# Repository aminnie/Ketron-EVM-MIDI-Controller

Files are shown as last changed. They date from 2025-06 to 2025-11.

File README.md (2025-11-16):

# Ketron EVM Arranger MIDI Controller

This MIDI Controller for the Ketron EVM Sound Module is based on the Adafruit MacroPad RP2040 circuit board:
 
- Adadfruit kits supported: 
   - Macropad Starter kit at https://www.adafruit.com/product/5128 or the
   - Macropad Barebones board at https://www.adafruit.com/product/5100
- Learning more about the Macropad, assembly instructions, and how to download custom code into the device: https://learn.adafruit.com/adafruit-macropad-rp2040. 
- The Starter kit can also be purchased from vendors such as Digikey: https://www.digikey.com/en/products/detail/adafruit-industries-llc/5128/14635377
- Adafruit Midi Library: https://docs.circuitpython.org/projects/midi/en/latest/api.html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
- The Starter kit is an assembly only, and requires no soldering or electronics experience.

The EVM Pad controller is embedded in a custom 3d printed case with low profile key switches and LED window keycaps:

EVMPad

Why use the Macropad RP2040 to control the Ketron? The Macropad has USB HID keyboard drivers - just like the countless keypads you fill find on Amazon. However, these devices and many dedicated MIDI controllers do not support sending MIDI SysEx messages. Ketron exposes a hardware MIDI pedal interface on the EVM, but also has generously provided a MIDI over USB implmenetation. This controller is coded to send MIDI CC and SysEX messages over USB using the Adafruit Circuit Python library.

## EVM Controller HS13+ (Plus):

### Controller Button Configuration

The USB based MIDI Controller supports the most often used Arranger functions via MIDI SysEx and CC messages. Button assignments can be changed by modifying the values in a config file saved on the controller's USB drive. The controller supports a base and shift layer, enabling up to 24 functions to be coded on the keys. 

#### Base layer key assignments

The base layer of the controller is configured to the following EVM SysEx messages:

Row 1:
- Intro/End 1 (green)
- Intro/End 2 (green)
- Intro/End 3 (green)
- To End (red)

Row 2:
- Arr.A (blue)
- Arr.B (blue)
- Arr.C (blue)
- Arr.D (blue)

Row 3:
- Variation/Shift (blue)
- Fill (green)
- Break (orange)
- Start/End (red)

#### Shift layer key assignments

The shift layer of the controller is configured to the following EVM SysEx messages:

Row 1:
- Transpose Up (yellow)
- Transpose Down (yellow)
- Octave Up (teal)
- Octave Down (teal)

Row 2:
- 1/2 Bar (blue)
- Plugged (orange) (drums and bass only macro)
- UnPlugged (orange) (style, real chord and chord only macro)
- RHYTHM (blue) (Rhythm only macro)

Row 3:
- Variation/Shift (blue)
- Value Down (violet)
- Value Up (violet)
- Start/End (red)

#### Activating the Shift Layer
The shift layer operates in two modes - similar to a typical PC keyboard:
- Press the Variation/Shift key, and while holding it in follow up with a second key press for the desired layered function. This combination of keys will transmit the layered MIDI message. This allows for quick activations of e.g. the 1/2 Bar message using the familiar keyboard shift action. More than one layered massage can be sent while the original shift key is held down.
- When you press and hold Variation/Shift for 200ms or longer, the keypad behavior starts activating in a way similar to caps lock on a PC keyboard. The shift layer is activated and keys such as Value Up/Down can be pressed until the Variation/Shift key is pressed again.
- Note: The Variation key continues to support the EVM Arranger Variation function on a quick press (<200ms) and if the above shift conditions are not met.

### Controller Primary Encoder Configuration:

The Encoder switch is coded to cycle through the following functions when pressed. The rotary encode is used to change the values for the selected function.
- Rotor Fast/Slow (blue) - fast or slow, default
- Tempo Up/Down (yellow) - up or down from current Tempo value
- Master Volume Up/Down (purple)

Notes:
- The colors mentioned for the encoder show on the Variation key. When you press Start/Stop, the EVM will start playing and the Variation button turns yellow to indicate that it is in Tempo adjustment mode. The Tempo and Volume modes once activated or pressed are timed to return to the default Rotor Fast/Slow after 60 seconds of no adjustments.
- For Master Volume to work, you must change the EVM configuration to listen on MIDI channel 16. You can do so by navigating to the EVM MIDI configuration screen, select the receive (RX) option, and then set Global to channel 16. The Controller encoder in Volume mode sends MIDI CC Expression to EVM RX Global channel 16 adjusting the volume of all channels in the EVM - acting similar to the EVM Master Volume knob. Also note that an attached MIDI keyboard/organ can be configured to send expression pedal messages to the EVM synchronizing volume between the devices in the same manner.

### Connecting the EVM Controller to your EVM Module:

- The Ketron EVM expects all attached MIDI devices to be powered up before you start it up. It will not detect devices on the USB or MIDI ports that is not switched on or added after EVM power up.
- The Macropad has a single USB port that is used to connect to the EVM, and as a result of the EVM  power up connect requirement, we have to power it via a USB hub or a USB Y Datat and Power Splitter cable that provides external power. 
This is an example USB Hub that works:  Wenter 5 Ports USB 3.0 Hub (https://www.amazon.com/gp/product/B0BMFDLRSQ/ref=ewc_pr_img_1?smid=ATSSJE5RHO7GG&psc=1). The powered USB hub can also be used to charge a tablet if you use that to wirelessly control the EVM. Some Y-splitter USB cables may also work if you prefer to connect a cell phone charger battery for instance to power the unit. See https://www.amazon.com/s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

### Loading customized code into a new Adafruit controller:

See the Adafruit learning website for detailed instructors on how to
-  Prepare the board to load our custom solution in the boot.pym code.py and keymap.cfg files into the controller board.
-  You have the following options after the firmware has been loaded onto the new board:
   - Simply copy the code files from a local disk to the MacroPad USB drive mounted as 'CIRCUITPY'.
   - Use an text editor such as NotePad++ to open the extracted controller files from the download and do a Save-As into the CIRCUITPY drive. This often is the easiest and most reliable way way to update the controller code.
   - Download the Mu Editor to your PC. Mu will connect to the Macropad board and allow you up/download and edit the code.py file. It also has a REPL terminal that can be used to interact with the board during development and debugging and useful if you decide to modify the EVM controller code. 

### Testing the EVM Controller:

Before connecting to the EVM moodule, you may want to download and install MidiView (https://hautetechnique.com/midi/midiview/). MidiView is useful to inspect and validate the output from any MIDI controller. MidiView allows you to monitor the exchange of MIDI messages between any two devices. In this case you will see the EVM controller output the MIDI SysEx and CC messages associated with keys or the rotary encoder.

### Customizing the EVM Cntroller SysEx messages:

Keys are configured by updating the keymap.cfg file on the controller USB drive. Modifying the mappings requires you to lookup the exact text for the required SysEWx MIDI message from either the Tabs (pedal_midis) or Pedal (tab_midis) lookup tables in the Ketron MIDI documentation, and copy it onto one of the keys of the keys. See the config file for the current configuration. Please be careful with the configuration. It is validating and if an error is enountered during startup, all keys will turn red. The unit continues to function though based on the coded defaults. It is preferred that you keep with the Pedal messages. There are many more Tab messages, and for instance Value Up/Down is very useful, but without context it results in unexpected behaviors in the EVM. Carefully test if you pick a value from Tabs other than VARATION. 
Note: The rotary encoder SysEx output is currently hardcoded to tempo up/down,  rotary fast/slow or volume up/down on successive encoder button presses. It is not configurable, but could be done in future if requested.

## EVM Controller HS13+ (Plus):

This version of the EVM controller supports four additional quad encoders used to manage style and voice volumes. The additional four encoders and their built-in switches follow the shift state enabled through the Variation key as explained above. 

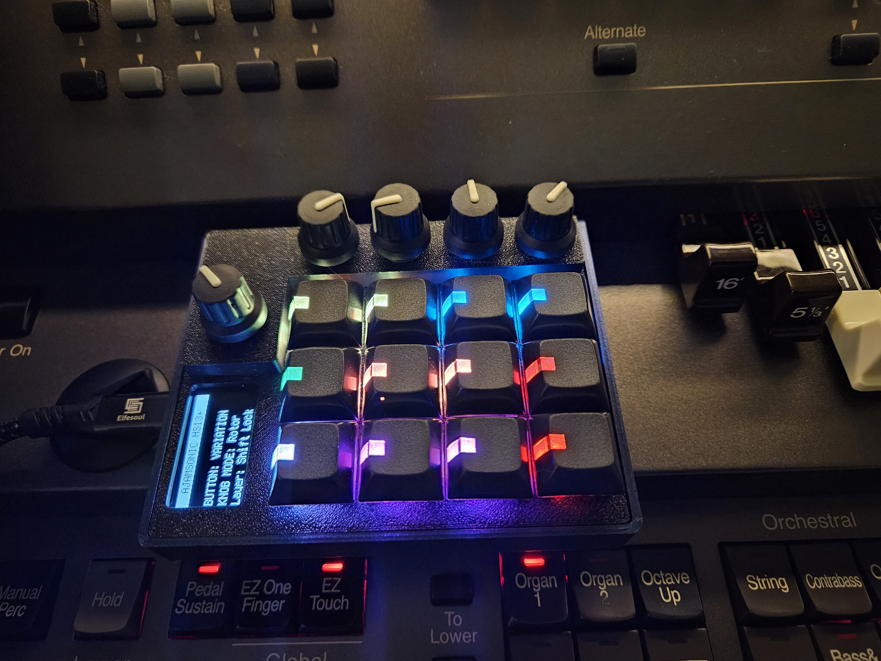
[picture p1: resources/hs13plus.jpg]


### Base layer encoder assignments

Rotary Encoders (left to right):
- Lowers Volume
- Upper/Voice 1 Volume
- Upper/Voice 2 Volume
- Drawbar Volume

Rotary Switches (on each encoder):
- Lowers Volume toggle 0 or 96
- Upper1 Volume toggle 0 or 96
- Upper2 Volume toggle 0 or 96
- Drawbar Volume toggle 0 or 96

### Shift layer encoder assignments

Rotary Encoders (left to right):
- Drum Volume
- Bass Volume
- Chord Volumes
- RealChord Volumes

Rotary Switches (on each encoder):
- Drum Volume toggle 0 or 96
- Bass Volumes toggle 0 or 96
- Chord Volumes toggle 0 or 96
- RealChord Volume toggle 0 or 96

Notes: 
- ‘All Style’ volumes include: Style, Drums, RealChord and Chord
- Volume settings are adjusted relative to the switches options pressed.

#### More versions of this controller:  
- A version of the controller code is also available that emits only MIDI CC messages for instruments that can be coded via MIDI CC messages.

#### Extra:

- Please let me know you need a 3D case for your solution
  - The 3D case .scad and .stl files are available in the case directory if you would like to print it yourself. There are multiple versions of the files for each of the HS13 and HS13+. Each case consists of 3 or more components to be printed.
  - We switched to using low profile key switches and caps you see in the picture. It feels and looks much better. Contact me if I can help.
  - If you plan to print a case and use low profile key switches, then I would recommend you buy the Adafruit Macropad bare bones board only, not the full kit
  - If you have a need to tinker with code.py and try qwiic add-ons, then print the dev 3D case which has a larger slot that accepts a qwiic connector.

Setup with the Roland AT900C, Ketron EVM, iPad EVM Controller, and the out of the box Macropad RP2040:



Original Adafruit Macropad RP2040:



Difference between the Adafruit MacroPad standard order and the custom ordered unit: Low profile key switches and custom key caps. A custom 3D printed case enclosure that hides the electronics components. And of course a MIDI controller solution customized for the Ketron Event series.

For more information, support, or a completed unit please contact: a_minnie@hotmail.com

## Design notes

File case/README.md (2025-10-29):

# Ketron EVM-Button-Controller Enclosure

More details and refinement of the OpenSCAD 3D (https://openscad.org/) design and code to follow.

The EVM HS13 AND HS13+ MacroPad controller enclosure consists of three components:
- Bottom case
  - The PCB and next two layers insert into the bottom case. 
  - The case has openings for the UCB connection as well as the Macropad reset.
- Top cover
  - Keys are inserted into the PCB using the top cover as guide. 
  - The top cover also hides the encoder main body with a seperately printed case (in a seperate file for the HS13)
- Filler layer
  - This layer is inserted in between the top cover laaer and the MacroPad PCB. This closes the gap between the top cover and the PCB and ensures that the latter remains correctly positions.

Assembly Instructions:
- 3D Print/order to print the three layers.
  - Check the opt cover encoder body part to ensure that it is clear of debris.
  - You may need a sharp knife or tool to clear our the encoder body, and a drill body to clean the 6mm shaft hole.
- Lay the top cover on filler layer. 
  - Note the filler layer has bigger openings for the keys than the top cover.
- Unscrew the encoder washer and nut.
- Place the filler layer, and top cover on the PCB, carefully placing the cover over the encoder main body.
  - Replace the encoder washer and nut you removed earlier and lightly tighten the it.
  - If you find that you are unable to get the nut to secure the top cover, then please revisit the step above and clear the top cover encoder body of extra print material.
  - Loosen the nut so that the cover top has a bit of play that helps with inserting the keyswitches
- Insert the 12 key switches into PCB going through the top cover.
  - The PCB has sockets for the keyswitches and no soldering is needed.
  - It will be a tight fir. Ensure you have a compatible key switch, that the pins are straight, and carefully position and insert the keys
  - I start with the middle row centers, followed by the outer corners.
- Insert the PCB assembly into the bottom case.
  - Ensure you have the USB connector aligned with the case USB opening!
  - Insert the PCB assembly at the LCD corner first so that Reset button goes into its respctive whole with out too much pressure
- Use 4 x 3mm screws to secure the bottom case to the PCB and the keyboard assembly.
  - To remobve the keyboard assembly, loosen all four screws, and remove the PCB out of the case by pushing the screws in.
- Insert the encoder knob onto the exposed shaft
  - Press the encoder button a few times and to ensure it is seated correctly.

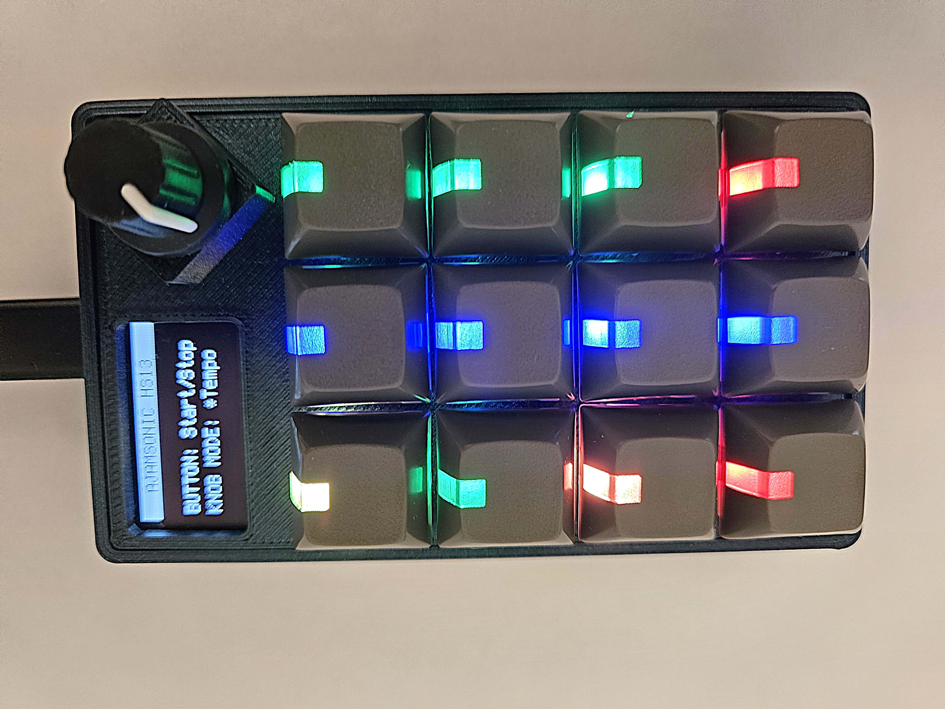
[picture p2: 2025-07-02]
resources/case_live.jpg

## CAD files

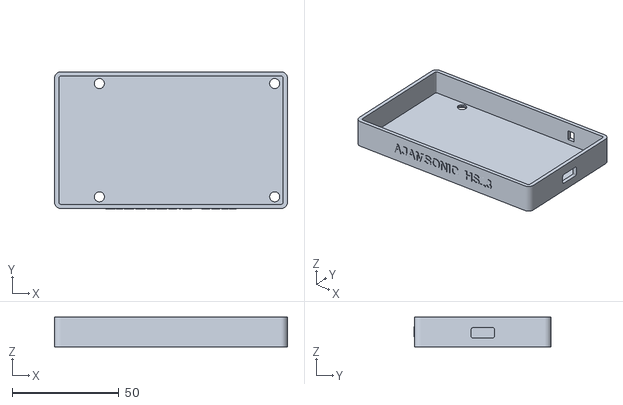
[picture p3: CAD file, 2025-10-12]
case/evm/case_logo.stl
109.0 x 64.3 x 14.0

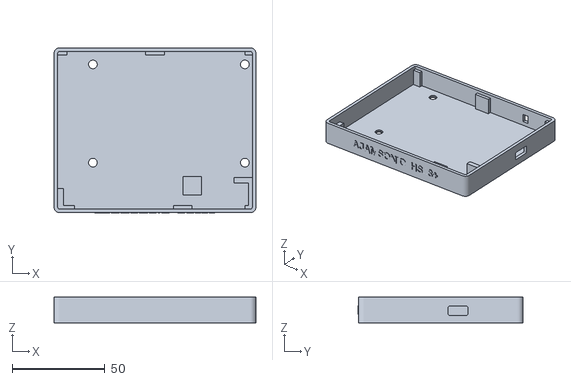
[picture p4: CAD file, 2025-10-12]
case/evmplus/case_plus.stl
109.0 x 89.3 x 14.0

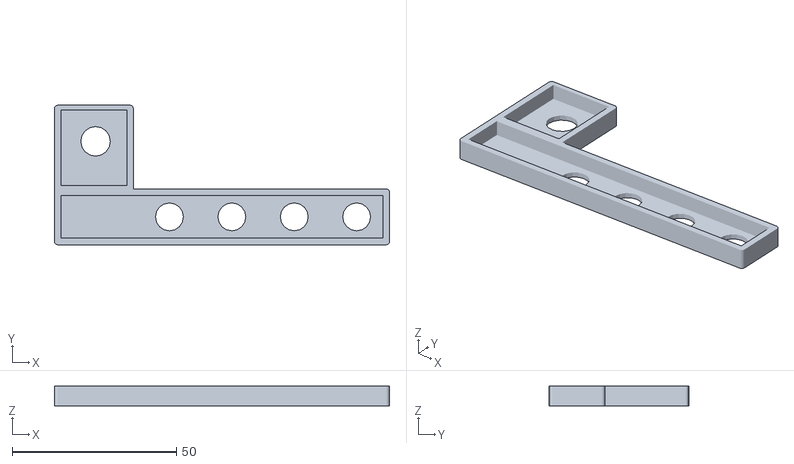
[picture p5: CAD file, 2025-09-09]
case/evmplus/topcover_plus_all_quad_cover.stl
102.0 x 42.5 x 6.00

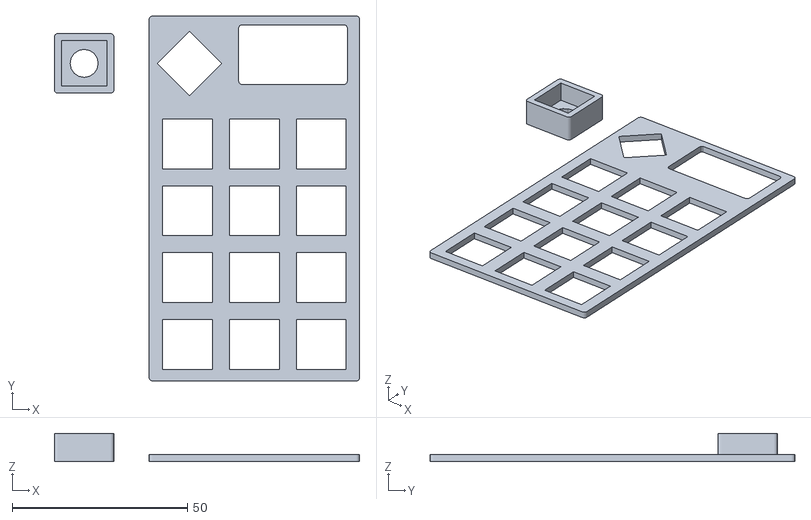
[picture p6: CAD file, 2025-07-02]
case/evm/topcover_reversed.stl
87.0 x 104.0 x 8.00

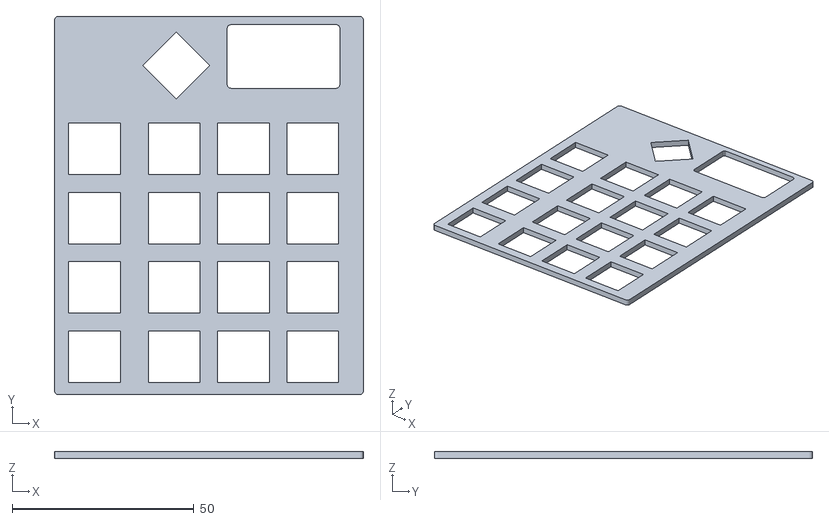
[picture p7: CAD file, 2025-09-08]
case/evmplus/topcover_plus_reversed.stl
85.0 x 104.0 x 2.00

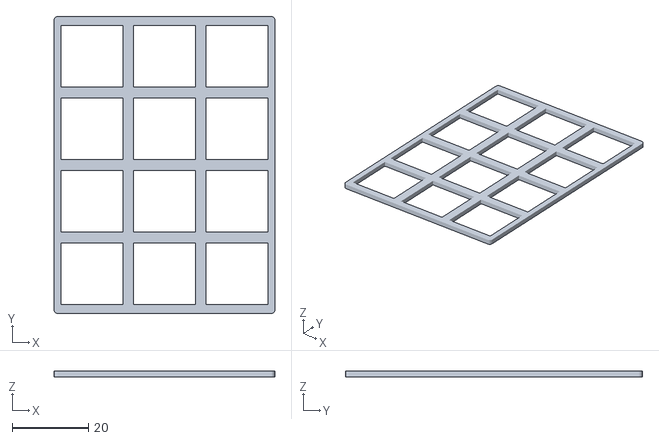
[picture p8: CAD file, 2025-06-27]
case/evm/cover_filler.stl
58.0 x 78.0 x 1.50

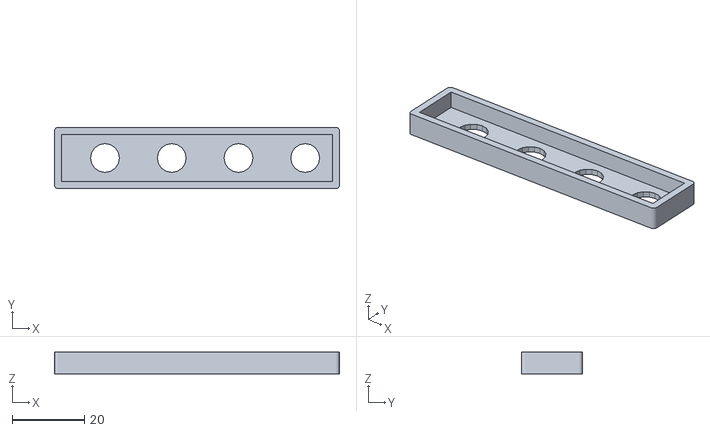
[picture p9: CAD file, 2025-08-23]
case/evmplus/topcover_plus_quad_cover.stl
79.0 x 17.0 x 6.00

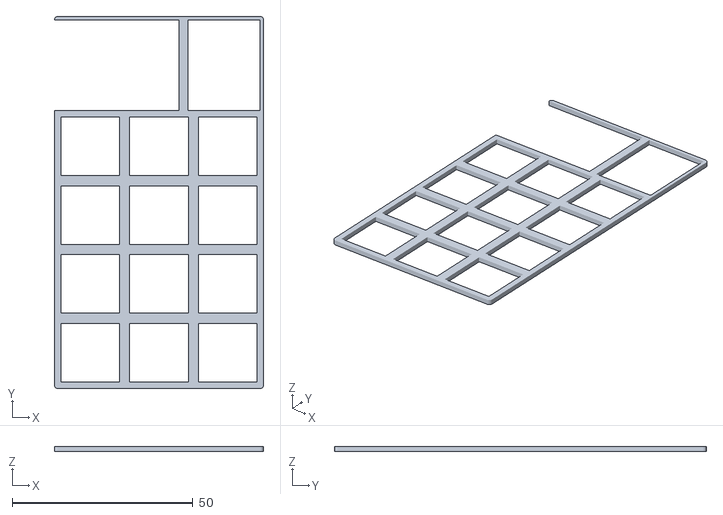
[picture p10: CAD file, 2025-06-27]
case/evm/cover_filler_support.stl
58.0 x 103.0 x 1.50

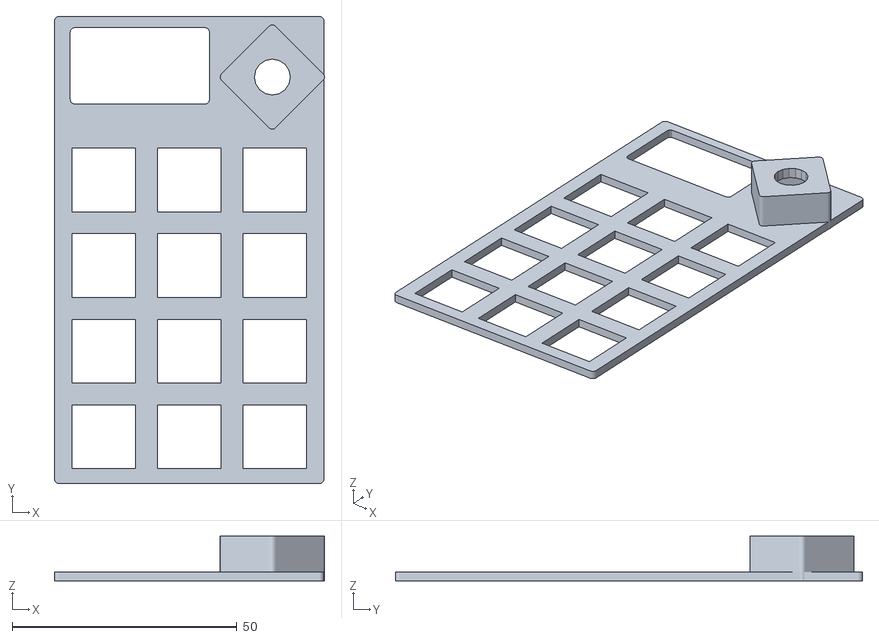
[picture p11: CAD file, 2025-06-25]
case/evm/topcover.stl
60.1 x 104.0 x 10.0

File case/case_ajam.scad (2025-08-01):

// MacroPad RP2040 Case (Bottom and Sides)
// Companion to macropad_top_cover.scad
// Parametric design for Adafruit MacroPad RP2040 keyboard controller
// Author: Generated for CircuitPython EVM Controller project
// License: MIT

// The bottom case along with the filler layer and cover OpenSCAD models provivided
// wraps the Adafruit MacroPad RP2040 in a tightfitting case. The case has a USB port
// the reset button opening, as well as 4 mounting holes to fasten the PCD to the case.

// =============================================================================
// PARAMETERS
// =============================================================================

// Adafruit Macropad RP2040 PCB parameters
pcb_length = 105;          // RP2040 PCB length (mm)
pcb_width = 60;            // RP2040 PCB width (mm)
pcb_thickness = 1.6;       // Standard PCB thickness (mm)
pcb_clearance = 1;         // Space around PCB (mm)
pcb_height_clearance = 8;  // Space above PCB for components (mm)

// Overall case dimensions (should match top cover)
bottom_thickness = 2;      // Thickness of bottom plate (mm)
wall_thickness = 2;        // Thickness of side walls (mm)
corner_radius = 3;         // Rounded corner radius (mm)
inner_corner_radius = 1;   // Rounded inner corner radius

case_length = pcb_length + (wall_thickness * 2);   // Total length of case (mm)
case_width = pcb_width + (wall_thickness * 2);  // Total width of case (mm)
case_height = 14;          // Height of case walls (mm)

// Top cover integration
top_cover_thickness = 3;   // Thickness of top cover (for fit calculation)
top_cover_lip = 1;         // How much top cover overlaps case walls (mm)

// USB port cutout
usb_width = 11;             // Width of USB-C port (mm)
usb_height = 5;            // ** Was 4 - Height of USB-C port (mm)
usb_offset_from_edge = 3;  // Distance from PCB edge to USB center (mm)
usb_position_y = 0;        // Y position along case width (0 = center)
usb_corner_radius = 1;     // Rounded corners for USB hole

// PCB mounting holes keep 2mm for wall in mind
mount_hole_diameter = 4.56;   // Diameter for M3 screws (mm)
mount_hole_positions = [   // [X, Y] positions relative to PCB center
    [-pcb_length/2 + 19, -26.5],   // Bottom left
    [pcb_length/2 - 4, -26.5],   // Bottom right  
    [-pcb_length/2 + 19, 26.5],    // Top left
    [pcb_length/2 - 4, 26.5]     // Top right
];

// Standoffs for PCB mounting
standoff_height = 6;         // Height of PCB standoffs (mm)
standoff_diameter = 5.2;     // Diameter of standoff base (mm)
standoff_hole_diameter = 2.5; // Hole diameter in standoff for screw (mm)

// 3D printing parameters
clearance = 0.2;           // General clearance (mm)
layer_height = 0.2;        // Your 3D printer layer height (mm)

// Catching indent for Cover support lip
cover_lip_indent = [10, 2.5, 2];


// =============================================================================
// MAIN OBJECT
// =============================================================================

difference() {
    union() {
        // Main case body
        case_body();

        ajam_text();
        
        // PCB mounting standoffs
        pcb_standoffs();
    }        

    // Remove internal cavity
    internal_cavity();

    // Remove USB port hole
    usb_port_hole();
    
    // Remove Reset port hole
    reset_port_hole();

    // Remove PCB mounting holes
    pcb_mounting_holes();
}

// Optional: Show PCB position for reference (comment out for final print)
// %pcb_reference();

// =============================================================================
// MODULES (Functions)
// =============================================================================

// Create the main case body with walls
module case_body() {
    // Bottom plate
    hull() {
        // Four corner cylinders for rounded rectangle base
        translate([-(case_length/2 - corner_radius), -(case_width/2 - corner_radius), 0])
            cylinder(h = bottom_thickness, r = corner_radius, $fn = 32);
        
        translate([+(case_length/2 - corner_radius), -(case_width/2 - corner_radius), 0])
            cylinder(h = bottom_thickness, r = corner_radius, $fn = 32);
        
        translate([+(case_length/2 - corner_radius), +(case_width/2 - corner_radius), 0])
            cylinder(h = bottom_thickness, r = corner_radius, $fn = 32);
        
        translate([-(case_length/2 - corner_radius), +(case_width/2 - corner_radius), 0])
            cylinder(h = bottom_thickness, r = corner_radius, $fn = 32);
    }
    
    // Side walls
    difference() {
        // Outer wall
        hull() {
            translate([-(case_length/2 - corner_radius), -(case_width/2 - corner_radius), 0])
                cylinder(h = case_height, r = corner_radius, $fn = 32);
            
            translate([+(case_length/2 - corner_radius), -(case_width/2 - corner_radius), 0])
                cylinder(h = case_height, r = corner_radius, $fn = 32);
            
            translate([+(case_length/2 - corner_radius), +(case_width/2 - corner_radius), 0])
                cylinder(h = case_height, r = corner_radius, $fn = 32);
            
            translate([-(case_length/2 - corner_radius), +(case_width/2 - corner_radius), 0])
                cylinder(h = case_height, r = corner_radius, $fn = 32);
        }
        
        // Inner cavity (removed in main difference)
        translate([0, 0, bottom_thickness])
            hull() {
                inner_radius = corner_radius - wall_thickness;
                inner_length = case_length - 2 * wall_thickness;
                inner_width = case_width - 2 * wall_thickness;
                
                translate([-(inner_length/2 - inner_radius), -(inner_width/2 - inner_radius), 0])
                    cylinder(h = case_height, r = inner_radius, $fn = 32);
                
                translate([+(inner_length/2 - inner_radius), -(inner_width/2 - inner_radius), 0])
                    cylinder(h = case_height, r = inner_radius, $fn = 32);
                
                translate([+(inner_length/2 - inner_radius), +(inner_width/2 - inner_radius), 0])
                    cylinder(h = case_height, r = inner_radius, $fn = 32);
                
                translate([-(inner_length/2 - inner_radius), +(inner_width/2 - inner_radius), 0])
                    cylinder(h = case_height, r = inner_radius, $fn = 32);
            }
    }
    
    // Top cover lip/ledge
    translate([0, 0, case_height - top_cover_thickness]) {
        difference() {
            // Outer ledge
            hull() {
                translate([-(case_length/2 - corner_radius), -(case_width/2 - corner_radius), 0])
                    cylinder(h = top_cover_thickness, r = corner_radius, $fn = 32);
                
                translate([+(case_length/2 - corner_radius), -(case_width/2 - corner_radius), 0])
                    cylinder(h = top_cover_thickness, r = corner_radius, $fn = 32);
                
                translate([+(case_length/2 - corner_radius), +(case_width/2 - corner_radius), 0])
                    cylinder(h = top_cover_thickness, r = corner_radius, $fn = 32);
                
                translate([-(case_length/2 - corner_radius), +(case_width/2 - corner_radius), 0])
                    cylinder(h = top_cover_thickness, r = corner_radius, $fn = 32);
            }
            
            // Inner cutout for top cover
            hull() {
                ledge_radius = corner_radius - top_cover_lip;
                ledge_length = case_length - 2 * top_cover_lip;
                ledge_width = case_width - 2 * top_cover_lip;
                
                translate([-(ledge_length/2 - ledge_radius), -(ledge_width/2 - ledge_radius), -0.5])
                    cylinder(h = top_cover_thickness + 1, r = ledge_radius, $fn = 32);
                
                translate([+(ledge_length/2 - ledge_radius), -(ledge_width/2 - ledge_radius), -0.5])
                    cylinder(h = top_cover_thickness + 1, r = ledge_radius, $fn = 32);
                
                translate([+(ledge_length/2 - ledge_radius), +(ledge_width/2 - ledge_radius), -0.5])
                    cylinder(h = top_cover_thickness + 1, r = ledge_radius, $fn = 32);
                
                translate([-(ledge_length/2 - ledge_radius), +(ledge_width/2 - ledge_radius), -0.5])
                    cylinder(h = top_cover_thickness + 1, r = ledge_radius, $fn = 32);
            }
        }
    }
}
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

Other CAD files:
case/evm/case_dev.stl
case/evm/case.stl
case/evm/case.scad
case/evm/case_dev.scad
case/evm/case_logo.scad
case/evm/cover_filler.scad
case/evm/cover_filler_support.scad
case/evm/macropad_topcover_reversed.scad
case/evm/topcover.scad
case/evm/topcover_reversed.scad
case/evmplus/case_plus.scad
case/evmplus/topcover_plus_all_quad_cover.scad
case/evmplus/topcover_plus_quad_cover.scad
case/evmplus/topcover_plus_reversed.scad
case/keycaps/evm_keycap_topcover_clear.scad
case/keycaps/evm_transparent_keycap_insert.scad
case/keycaps/roundedcubes.scad

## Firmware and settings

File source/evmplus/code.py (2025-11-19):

# Ketron EVM Arranger Controller - Plus

import board, displayio, digitalio
import terminalio
import time

from adafruit_display_text import bitmap_label as label
from adafruit_displayio_layout.layouts.grid_layout import GridLayout
from adafruit_macropad import MacroPad

import usb_midi
import adafruit_midi
from adafruit_midi.control_change import ControlChange
from adafruit_midi.note_off import NoteOff
from adafruit_midi.note_on import NoteOn
from adafruit_midi.system_exclusive import SystemExclusive

from rainbowio import colorwheel

import adafruit_seesaw.digitalio
import adafruit_seesaw.neopixel
import adafruit_seesaw.rotaryio
import adafruit_seesaw.seesaw

# Set to FALSE for no startup test
TEST_CONNECT = False

# --- Constants and Enums ---
class EncoderMode:
    ROTOR = 0
    TEMPO = 1
    VOLUME = 2
    VALUE = 3

class MIDIType:
    PEDAL = 0
    TAB = 1
    MACRO = 2
    
class MIDIStatus:
    OFF = 0x00
    ON = 0x7F

class EncoderMode:
    ROTOR = 0
    TEMPO = 1
    VOLUME = 2
    VALUE = 3

class ShiftKeyMode:
    OFF = 0
    PENDING = 1
    ACTIVE_SHIFT = 2
    ACTIVE_LOCK = 3

class EFXLevel:
    Voice1 = 0x07
    Voice2 = 0x3D
    RealChord = 0x08
    LeftGM = 0x3F

# Manage Control Panel Volume Sliders via midi CC
class SliderCC:
    PLAYER_CC = 0x66   #CC 102
    STYLE_CC = 0x67
    DRUM_CC = 0x68
    BASS_CC = 0x69
    CHORD_CC = 0x6A
    REALCHORD_CC = 0x6B
    LOWERS_CC = 0x6C
    USER2_CC = 0x6D
    USER3_CC = 0x6E
    VOICE1_CC = 0x72     #CC 114
    VOICE2_CC = 0x73
    DRAWBARS_CC = 0x74
    MICRO1_CC = 0x75
    VOCAL_CC = 0x76

class Colors:
    WHITE = 0x606060
    BLUE = 0x000020
    GREEN = 0x002000
    RED = 0x200000
    ORANGE = 0x701E02
    PURPLE = 0x800080
    YELLOW = 0x808000
    TEAL = 0x004040
    OFFWHITE = 0xA47474

# Color mapping dictionary
COLOR_MAP = {
    'red': Colors.RED,
    'green': Colors.GREEN,
    'blue': Colors.BLUE,
    'purple': Colors.PURPLE,
    'yellow': Colors.YELLOW,
    'orange': Colors.ORANGE,
    'white': Colors.WHITE,
    'teal': Colors.TEAL,
    'offwhite': Colors.OFFWHITE
}

# Key used to trigger test tune
TUNE_KEY = 11

# --- Configuration Class ---
class EVMConfig:
    def __init__(self):
        #self.display_banner =     "   Ketron EVM Plus   "
        #self.display_sub_banner = "Arranger Controller "
        #self.version = "1.2"
        self.display_banner =     "   AJAMSONIC HS13+   "
        self.display_sub_banner = "Pad Controller   "
        self.version = "1.2.0"

        # USB port on the left side of the MacroPad
        self.usb_left = True

        # MIDI Out Channel to be matched in EVM Global RX
        self.midi_out_channel = 15
        
        # Key used to reflect timed Eccoder mode changes on LED
        # Enable or disable Layer Shift Mode for users who prefer single layer only 
        self.key_variation = 0
        self.shift_enable = True

        # Timers for tempo, volume, key brightness, etc
        self.key_bright_timer = 0.20
        self.shift_hold_timer = 0.25

        self.tempo_timer = 60
        self.volume_timer = 60
        self.value_timer = 60
        self.version_timer = 15
        self.tune_hold_timer = 2
        
        # Quad Encoder configs loaded from keymap.cfg
        self.is_quadencoder = True
        self.encoder_step = 8
        self.encoder_fwd = True
        self.encoder_grad = False
        self.encoder_vol = 96

        self.quad_switch_timer = .5
        
        # Quad encoder variables
        self.quad_encoders = []
        self.quad_switches = []
        self.quad_switches_toggle = []
        self.quad_pixels = []

        # Initialize MacroPad key mappings
        self.key_map = [0, 1, 2, 3, 4, 5, 6, 7, 8, 9, 10, 11]
        if not self.usb_left:
            self.key_map = [11 - i for i in range(12)]

    def get_key(self, key):
        """Safe key mapping with bounds checking"""
        
        if key < 0 or key > 11:
            print("Invalid key map request: {}".format(key))
            return 0
        return self.key_map[key]

# --- MIDI Handler Class ---
class MIDIHandler:
    def __init__(self, midi_instance, config, key_cache):
        self.midi = midi_instance
        self.config = config
        self.key_cache = key_cache
        
        self.manufacturer_id_pedal = bytearray([0x26, 0x79])
        self.manufacturer_id_tab = bytearray([0x26, 0x7C])
        self.manufacturer_id_efx = bytearray([0x26, 0x7B])
        
        # Pre-allocate bytearrays for memory efficiency
        self.pedal_sysex_1 = bytearray([0x03, 0x00, 0x00])
        self.pedal_sysex_2 = bytearray([0x05, 0x00, 0x00, 0x00])
        self.tab_sysex = bytearray([0x00, 0x00])

        # EFX Level/Volume
        self.efx_level_sysex = bytearray([0x00, 0x05, 0x00])

        self.cur_volume = 100

    def send_pedal_sysex(self, midi_value):
        """Send SysEx for Pedal commands"""
        
        try:
            # Send ON followed by OFF Message
            if midi_value < 128:
                self.pedal_sysex_1[1] = midi_value
                self.pedal_sysex_1[2] = MIDIStatus.ON
                sysex_message = SystemExclusive(self.manufacturer_id_pedal, self.pedal_sysex_1)
                self.midi.send(sysex_message)

                self.pedal_sysex_1[2] = MIDIStatus.OFF
                sysex_message = SystemExclusive(self.manufacturer_id_pedal, self.pedal_sysex_1)
                self.midi.send(sysex_message)
            else:
                self.pedal_sysex_2[1] = (midi_value >> 7) & 0x7F
                self.pedal_sysex_2[2] = midi_value & 0x7F
                self.pedal_sysex_2[3] = MIDIStatus.ON
                sysex_message = SystemExclusive(self.manufacturer_id_pedal, self.pedal_sysex_2)
                self.midi.send(sysex_message)

                self.pedal_sysex_2[3] = MIDIStatus.OFF
                sysex_message = SystemExclusive(self.manufacturer_id_pedal, self.pedal_sysex_2)
                self.midi.send(sysex_message)
            return True
        except Exception as e:
            print("Error sending pedal SysEx: {}".format(e))
            return False

    def send_tab_sysex(self, midi_value):
        """Send SysEx for Tab commands"""
        
        try:
            self.tab_sysex[0] = midi_value
            self.tab_sysex[1] = MIDIStatus.ON
            sysex_message = SystemExclusive(self.manufacturer_id_tab, self.tab_sysex)
            self.midi.send(sysex_message)

            self.tab_sysex[1] = MIDIStatus.OFF
            sysex_message = SystemExclusive(self.manufacturer_id_tab, self.tab_sysex)
            self.midi.send(sysex_message)
            return True
        except Exception as e:
            print("Error sending tab SysEx: {}".format(e))
            return False

    def send_macro_sysex(self, midi_key):
        """Send one or more macro list values as SysEx Pedal or Tab message(s)"""

        try:
            
            for macro, items in self.key_cache.user_macro_midis.items():
                #print(f"Macro: {macro}")
                if macro == midi_key:
                    for item in items:
                        #print(f"  - {item}")
                        if ':' in item:
                            macro_parts = item.split(':')
                            #print(f"macro_parts: {macro_parts}")
                            if len(macro_parts) >= 2:
                                lookup_key = int(macro_parts[0].strip())
                                value = macro_parts[1].strip()

                                if lookup_key == MIDIType.PEDAL:
                                    hex_value = self.key_cache.pedal_midis.get(value, "")
                                    if hex_value:
                                        self.send_pedal_sysex(hex_value)
                                elif lookup_key == MIDIType.TAB:
                                    hex_value = self.key_cache.tab_midis.get(value, "")                            
                                    if hex_value:
                                        self.send_tab_sysex(hex_value)
            return True
        except Exception as e:
            print("Error sending macros SysEx: {}".format(e))
            return False

    def send_master_volume(self, config, updown):
        """Send volume control via CC11"""
        self.config = config
        
        try:
            # Change volume in 8-unit increments
            if updown == -1:
                self.cur_volume = max(0, self.cur_volume - 8)
            else:
                self.cur_volume = min(127, self.cur_volume + 8)

            self.midi.send(ControlChange(11, self.cur_volume), channel=self.config.midi_out_channel)
            return True
        except Exception as e:
            print("Error sending volume: {}".format(e))
            return False

    def send_quad_volume(self, config, volume):
        """Send volume CC for Quad Encoder on special EVM CCs"""
        self.config = config
        
        try:
            self.midi.send(ControlChange(11, volume), self.config.midi_out_channel)
        except Exception as e:
            print("Error sending volume: {}".format(e))
            return False        

    def send_quad_cc_volume(self, ccCode, volume, midi_channel):
        """Send volume CC for Quad Encoder configured channels"""
        
        try:
            self.midi.send(ControlChange(ccCode, volume), midi_channel)
        except Exception as e:
            print("Error sending volume: {}".format(e))
            return False        

    def send_efxlevel_sysex(self, efxcode, volume):
        """Send SysEx EFX Level/Volume commands"""
        
        try:
            self.efx_level_sysex[0] = efxcode
            self.efx_level_sysex[2] = volume
            sysex_message = SystemExclusive(self.manufacturer_id_efx, self.efx_level_sysex)
            self.midi.send(sysex_message)

            return True
        except Exception as e:
            print("Error sending EFX Level SysEx: {}".format(e))
            return False

    def test_connectivity(self):
        """Test MIDI connectivity with audible notes"""
        
        try:
            # Notes for a short segment of "Ode to Joy"
            # Using MIDI note numbers (C4=60, D4=62, E4=64, F4=65, G4=67, A4=69, B4=71, C5=72)
            notes = [64, 64, 65, 67, 67, 65, 64, 62, 60, 60, 62, 64, 64, 62, 62] 
            durations = [0.4] * len(notes)       

            for note, duration in zip(notes, durations):
                self.midi.send(NoteOn(note, 120))
                time.sleep(duration)
                self.midi.send(NoteOff(note, 0))
                time.sleep(duration/4)
            return True
        except Exception as e:
            print("MIDI test failed: {}".format(e))
            return False

# --- Key Lookup Cache for Performance ---
class KeyLookupCache:
    def __init__(self, config):
        self.config = config
        self.cache = {}
        self.cache_shift = {}

        # Initialize MacroPad key & color mappings to default MIDI message values
        # USB drive keymap.cfg file will override if present
        self.macropad_key_map = [
            "1:VARIATION", "0:Arr.A", "0:Intro/End1", "0:Fill",
            "0:Arr.B", "0:Intro/End2","0:Break", "0:Arr.C",
            "0:Intro/End3", "0:Start/Stop", "0:Arr.D", "0:To End"
        ]
        self.macropad_color_map = [
            Colors.BLUE, Colors.BLUE, Colors.GREEN, Colors.GREEN,
            Colors.BLUE, Colors.GREEN, Colors.ORANGE, Colors.BLUE,
            Colors.GREEN, Colors.RED, Colors.BLUE, Colors.RED
        ]

        self.macropad_key_map_shift = [
            "1:VARIATION", "0:Low. Mute", "1:TRANSP_DOWN", "0:HALF BAR",
            "0:FILL & DRUM IN", "1:TRANSP_UP", "0:Arr.Off", "2:UNPLUGGED",
            "1:OCTAVE_DOWN", "0:Start/Stop", "2:PLUGGED", "1:OCTAVE_UP"
        ]
        self.macropad_color_map_shift = [
            Colors.RED, Colors.BLUE, Colors.YELLOW, Colors.PURPLE,
            Colors.GREEN, Colors.YELLOW, Colors.RED, Colors.ORANGE,
            Colors.TEAL, Colors.RED, Colors.ORANGE, Colors.TEAL
        ]

        self.user_macro_midis = {
            "UNPLUGGED":["0:FILL & DRUM IN"],
            "PLUGGED":["0:Drum Mute"],
            "FArr.A":["1:FILL","0:Arr.A"],
            "FArr.B":["1:FILL","0:Arr.B"],
            "FArr.C":["1:FILL","0:Arr.C"],
            "FArr.D":["1:FILL","0:Arr.D"],
            "SStop":["0:Start/Stop"],
            "SStop":["0:Start/Stop"],
            "SStop":["0:Start/Stop"],
            "SStop":["0:Start/Stop"]
        }

        # Ketron Pedal and Tab MIDI lookup dictionaries
        self.pedal_midis = self._init_pedal_midis()
        self.tab_midis = self._init_tab_midis()
        self.cc_midis = self._init_cc_midis()

        self._build_cache()

    def _init_pedal_midis(self):
        """Initialize pedal MIDI dictionary"""
        
        return {
            "Sustain": 0x00, "Soft": 0x01, "Sostenuto": 0x02, "Arr.A": 0x03,
            "Arr.B": 0x04, "Arr.C": 0x05, "Arr.D": 0x06, "Fill1": 0x07,
            "Fill2": 0x08, "Fill3": 0x09, "Fill4": 0x0A, "Break1": 0x0B,
            "Break2": 0x0C, "Break3": 0x0D, "Break4": 0x0E, "Intro/End1": 0x0F,
            "Intro/End2": 0x10, "Intro/End3": 0x11, "Start/Stop": 0x12,
            "Tempo Up": 0x13, "Tempo Down": 0x14, "Fill": 0x15, "Break": 0x16,
            "To End": 0x17, "Bass to Lowest": 0x18, "Bass to Root": 0x19,
            "Live Bass": 0x1A, "Acc.BassToChord": 0x1B, "Manual Bass": 0x1C,
            "Voice Lock Bass": 0x1D, "Bass Mono/Poly": 0x1E, "Dial Down": 0x1F,
            "Dial Up": 0x20, "Auto Fill": 0x21, "Fill to Arr.": 0x22,
            "After Fill": 0x23, "Low. Hold Start": 0x24, "Low. Hold Stop": 0x25,
            "Low. Hold Break": 0x26, "Low. Stop Mute": 0x27, "Low. Mute": 0x28,
            "Low. and Bass": 0x29, "Low. Voice Lock": 0x2A, "Pianist": 0x2B,
            "Pianist Auto/Stand.": 0x2C, "Pianist Sustain": 0x2D, "Bassist": 0x2E,
            "Bassist Easy/Exp.": 0x2F, "Key Start": 0x30, "Key Stop": 0x31,
            "Enter": 0x32, "Exit": 0x33, "Registration": 0x34, "Fade": 0x35,
            "Harmony": 0x36, "Octave Up": 0x37, "Octave Down": 0x38,
            "RestartCount In": 0x39, "Micro1 On/Off": 0x3A, "Micro1 Down": 0x3B,
            "Micro1 Up": 0x3C, "Voicetr.On/Off": 0x3D, "Voicetr.Down": 0x3E,
            "Voicetr.Up": 0x3F, "Micro2 On/Off": 0x40, "EFX1 On/Off": 0x41,
            "EFX2 On/Off": 0x42, "Arabic.Set1": 0x43, "Arabic.Set2": 0x44,
            "Arabic.Set3": 0x45, "Arabic.Set4": 0x46, "Dry On Stop": 0x47,
            "Pdf Page Down": 0x48, "Pdf Page Up": 0x49, "Pdf Scroll Down": 0x4A,
            "Pdf Scroll Up": 0x4B, "Glide Down": 0x4C, "Lead Mute": 0x4D,
            "Expr. Left/Style": 0x4E, "Arabic Reset": 0x4F, "Hold": 0x50,
            "2nd On/Off": 0x51, "Pause": 0x52, "Talk On/Off": 0x53,
            "Manual Drum": 0x54, "Kick Off": 0x55, "Snare Off": 0x56,
            "Rimshot Off": 0x57, "Hit-Hat Off": 0x58, "Cymbal Off": 0x59,
            "Tom Off": 0x5A, "Latin1 Off": 0x5B, "Latin2 Off": 0x5C,
            "Latin3/Tamb Off": 0x5D, "Clap/fx Off": 0x5E, "Voice Down": 0x5F,
            "Voice Up": 0x60, "Regis Down": 0x61, "Regis Up": 0x62,
            "Style Voice Down": 0x63, "Style Voice Up": 0x64, "EFX1 Preset Down": 0x65,
            "EFX1 Preset Up": 0x66, "Multi": 0x67, "Page<<": 0x68, "Page>>": 0x69,
            "RegisVoice<<": 0x6A, "RegisVoice>>": 0x6B, "Text Page": 0x6E,
            "Text Page+": 0x6F, "Style Voice 1": 0x70, "Style Voice 2": 0x71,
            "Style Voice 3": 0x72, "Style Voice 4": 0x73, "VIEW & MODELING": 0x74,
            "Lock Bass": 0x75, "LockChord": 0x76, "Lyrics": 0x77,
            "VoiceToABCD": 0x87, "TAP": 0x88, "Autocrash": 0x89,
            "Transp Down": 0x8A, "Transp Up": 0x8B, "Text Record": 0x8C,
            "Bass & Drum": 0x8D, "Pdf Clear": 0x8E, "Record": 0x90, "Play": 0x91,
            "DoubleDown": 0x92, "DoubleUp": 0x93, "Arr.Off": 0x94,
            "FILL & DRUM IN": 0x95, "Wah to Pedal": 0x96, "Overdrive to Pedal": 0x98,
            "Drum Mute": 0x99, "Bass Mute": 0x9A, "Chords Mute": 0x9B,
            "Real Chords Mute": 0x9C, "Voice2 to Pedal": 0x9D, "Micro Edit": 0x9E,
            "Micro2 Edit": 0x9F, "HALF BAR": 0xA0, "Bs Sust Pedal": 0xA1,
            "Scale": 0xA2, "End Swap": 0xA3, "Set Down": 0xA4, "Set Up": 0xA5,
            "FswChDelay": 0xA6, "IntroOnArr.": 0xA7, "EndingOnArr.": 0xA8,
            "Arr. Down": 0xA9, "Arr. Up": 0xAA, "Ending1": 0xAB, "Ending2": 0xAC,
            "Ending3": 0xAD, "Bass Lock": 0xAE, "Intro Loop": 0xB0,
            "Scene Down": 0xB1, "Scene Up": 0xB2, "STEM Scene A": 0xB3,
            "STEM Scene B": 0xB4, "STEM Scene C": 0xB5, "STEM Scene D": 0xB6,
            "STEM Solo": 0xB7, "STEM Autoplay": 0xB8, "STEM A On/Off": 0xB9,
            "STEM B On/Off": 0xBA, "STEM C On/Off": 0xBB, "STEM D On/Off": 0xBC,
            "STEM Lead On/Off": 0xBD, "Art. Toggle": 0xBE, "Key Tune On/Off": 0xBF,
            "Txt Clear": 0xC0, "Voicetr. Edit": 0xC1, "Clear Image": 0xC2
        }

    def _init_tab_midis(self):
        """Initialize tab MIDI dictionary"""
        
        return {
            "DIAL_DOWN": 0x0, "DIAL_UP": 0x1, "PLAYER_A": 0x2, "PLAYER_B": 0x3,
            "ENTER": 0x4, "MENU": 0x6, "LYRIC": 0x7, "LEAD": 0x8, "VARIATION": 0x9,
            "DRAWBARS_VIEW": 0x0a, "DRAWBARS": 0x10, "DRUMSET": 0x11, "TALK": 0x12,
            "VOICETRON": 0x13, "STYLE_BOX": 0x14, "VOICE1": 0x19, "VOICE2": 0x1a,
            "USER_VOICE": 0x1b, "XFADE": 0x1c, "INTRO1": 0x1d, "INTRO2": 0x1e,
            "INTRO3": 0x1f, "BASSIST": 0x20, "DRUM_MIXER": 0x22, "OCTAVE_UP": 0x24,
            "OCTAVE_DOWN": 0x25, "USER_STYLE": 0x26, "DSP": 0x27, "ADSR_FILTER": 0x28,
            "MICRO": 0x29, "ARRA": 0x2c, "ARRB": 0x2d, "ARRC": 0x2e, "ARRD": 0x2f,
            "FILL": 0x30, "BREAK": 0x31, "JUKE_BOX": 0x32, "STEM": 0x33,
            "PIANIST": 0x34, "BASS_TO_LOWEST": 0x40, "MANUAL_BASS": 0x41,
            "PORTAMENTO": 0x48, "HARMONY": 0x49, "PAUSE": 0x4a, "TEMPO_SLOW": 0x4b,
            "TEMPO_FAST": 0x4c, "START_STOP": 0x4d, "TRANSP_DOWN": 0x59,
            "TRANSP_UP": 0x5a, "AFTERTOUCH": 0x5e, "EXIT": 0x5f, "ROTOR_SLOW": 0x60,
            "ROTOR_FAST": 0x61, "PIANO_FAM": 0x62, "ETHNIC_FAM": 0x63,
            "ORGAN_FAM": 0x64, "GUITAR_FAM": 0x65, "BASS_FAM": 0x66,
            "STRING_FAM": 0x67, "BRASS_FAM": 0x68, "SAX_FAM": 0x69, "HOLD": 0x6f,
            "PAD_FAM": 0x70, "SYNTH_FAM": 0x71, "FADEOUT": 0x73, "BASS_TO_ROOT": 0x74,
            "GM": 0x77
        }

    def _init_cc_midis(self):
        """Initialize MIDI CC dictionary"""
        
        return {
            "PLAYER": SliderCC.PLAYER_CC, "STYLE": SliderCC.STYLE_CC, "DRUM": SliderCC.DRUM_CC, 
            "CHORD": SliderCC.CHORD_CC, "REALCHORD": SliderCC.REALCHORD_CC, 
            "BASS": SliderCC.BASS_CC, "LOWERS": SliderCC.LOWERS_CC, "USER2": SliderCC.USER2_CC, "USER3": SliderCC.USER3_CC, 
            "VOICE1": SliderCC.VOICE1_CC, "VOICE2": SliderCC.VOICE2_CC, "DRAWBARS": SliderCC.DRAWBARS_CC,
            "MICRO1": SliderCC.MICRO1_CC, "VOCAL": SliderCC.VOCAL_CC
    }


    def _build_cache(self):
        """Build lookup cache at startup"""
        
        # Build Default layer cache
        for i in range(12):
            key_id = self.config.get_key(i)
            mapped_key = self.macropad_key_map[key_id]

            if mapped_key and len(mapped_key) > 2 and mapped_key[1] == ':':
                try:
                    lookup_key = int(mapped_key[0])
                    midi_key = mapped_key[2:]

                    if lookup_key == MIDIType.PEDAL:
                        midi_value = self.pedal_midis.get(midi_key, 0)
                    else:
                        midi_value = self.tab_midis.get(midi_key, 0)

                    self.cache[i] = (lookup_key, midi_key, midi_value)
                except (ValueError, IndexError):
                    print("Error caching key {}: {}".format(i, mapped_key))
                    self.cache[i] = (0, "", 0)
            else:
                self.cache[i] = (0, "", 0)

        # Build Shift Layer cache
        for i in range(12):
            key_id = self.config.get_key(i)
            mapped_key = self.macropad_key_map_shift[key_id]

            if mapped_key and len(mapped_key) > 2 and mapped_key[1] == ':':
                try:
                    lookup_key = int(mapped_key[0])
                    midi_key = mapped_key[2:]

                    if lookup_key == MIDIType.PEDAL:
                        midi_value = self.pedal_midis.get(midi_key, 0)
                    else:
                        midi_value = self.tab_midis.get(midi_key, 0)

                    self.cache_shift[i] = (lookup_key, midi_key, midi_value)
                except (ValueError, IndexError):
                    print("Error caching shift key {}: {}".format(i, mapped_key))
                    self.cache_shift[i] = (0, "", 0)
            else:
                self.cache_shift[i] = (0, "", 0)

    def get_key_midi(self, key_id, shift_mode):
        """Get cached MIDI data for key"""
        
        if (shift_mode == ShiftKeyMode.ACTIVE_SHIFT) or (shift_mode == ShiftKeyMode.ACTIVE_LOCK):
            return self.cache_shift.get(key_id, (0, "", 0))
        else:
            return self.cache.get(key_id, (0, "", 0))

    def validate_color_string(self, color_string):
        """Validate and return color code"""
        
        return COLOR_MAP.get(color_string.lower(), Colors.WHITE)
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

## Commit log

2025-03-27 Update code.py
    Add Encoder switch to alternate between Tempo and Dial Up/Down SysEx messages
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2025-04-30 Updated Rotary Dial to support both ROTOR and TEMPO
    Use rotory dail click function to toggle between functions.
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2025-06-15 Default keysconfig.txt
    [keysconfig.txt]
2025-06-16 Update keysconfig.txt to handle key color spec
    [keysconfig.txt]
2025-06-17 Update after code review refactoring
    [keysconfig.txt]
2025-06-17 Update README.md and Code Refactoring/Optimization
    # EVMController.py - Code Review and Implementation Changes
    # Date: January 2025
    # CircuitPython/Python 2.7 Optimization for Ketron EVM Controller
    ## OVERVIEW
    This document outlines the comprehensive refactoring and optimization of EVMController.py
    for improved performance, maintainability, and robustness in CircuitPython environments.
    ## 🏗️ STRUCTURAL IMPROVEMENTS IMPLEMENTED
    ### 1. Configuration Management
    **NEW: EVMConfig Class**
    - Centralized all configuration settings (timers, display text, USB orientation)
    - Safe key mapping with bounds checking and error handling
    - **FIXED: 180-degree key rotation** - Physical la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
2025-06-18 Fixed error when the keys config file missing
    [code.py]
2025-06-18 Initial commit
    Cursor and Claude generated case first pass
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2025-06-18 Rename source code directory
    [keysconfig.txt]
2025-06-18 Renamed to .scad
    [macropad_case.scad, macropad_topcover.scad]
2025-06-19 Updated initial case designs
    [macropad_case.scad, macropad_topcover.scad]
2025-06-19 Update before first print
    [macropad_case.scad, macropad_topcover.scad]
2025-06-21 Updated case and case top
    [macropad_case.scad, macropad_case.stl, macropad_topcover.scad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]
2025-06-22 Case and top cover V1.0
    [macropad_case.scad, macropad_case.stl, macropad_topcover.scad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]
2025-06-22 Case refinement updates - case mounting holes
    [macropad_case.scad, macropad_case.stl, macropad_topcover.scad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]
2025-06-23 Created new cover filler to close gap between board and cover
    [cover_filler.scad, cover_filler.stl]
2025-06-24 Created QWIIC + reset slot. Took the right side case feet in 0.5mm for better fit to board.
    [macropad_case.stl, macropad_case_dev.scad, macropad_case_dev.stl]
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2025-06-25 Case incremental update
    [macropad_case.stl, macropad_topcover.scad, macropad_topcover.stl]
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2025-06-27 Added more extensive filler layer option
    [cover_filler.stl, cover_filler_support.scad, cover_filler_support.stl]
2025-07-02 Added comments to the OpenSCAD files
    [cover_filler.scad, cover_filler_support.scad, macropad_case.scad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]
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2025-07-02 Created a new reverse cover with bottom up
    [macropad_topcover_reversed.scad, macropad_topcover_reversed.stl]
2025-07-04 Add AJAMSONIC banner
    [keysconfig.txt]
2025-07-12 Renamed the case files
    [case.scad, case.stl, case_dev.scad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]
2025-07-21 Update the development case to enlarge the I2C port
    [case_dev.scad, case_dev.stl]
2025-07-30 Created Genos Controller
    [keysconfig.txt]
2025-08-01 Initial working version of the Genos Controller
    [case_ajam.scad, case_ajam.stl, keysconfig.txt]
2025-08-02 Quad Encoder Initialization volume reset on init
    [code.py]
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2025-08-05 Logo add to case
    [case_ajam.stl, case_logo.scad, case_logo.stl]
2025-08-10 EVM Plus new case
    [case_plus.scad, case_plus.stl, topcover_plus_reversed.scad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]
2025-08-16 Corrected Genos key to note mappings
    [code.py]
2025-08-17 Added layered key configs
    [keysconfig.txt]
2025-08-17 Changed key config file name for new adds
    [keymap.cfg, keysconfig.txt]
2025-08-18 Changed key config file name for new layer adds
    [keymap.cfg]
2025-08-18 Update keys config file removing error in mappings
    [keymap.cfg]
2025-08-19 Corrected a lookup issue in Genos controller
    [keysconfig.txt]
2025-08-23 New Quad Encoder increment limits added. Quad casing first iteration
    [topcover_plus_quad_cover.scad, topcover_plus_quad_cover.stl]
2025-08-24 Reworked Quad Encoder case
    [case_plus.scad, case_plus.stl]
2025-08-24 Added extra supports to Quad Encoder case
    [case_plus.scad, case_plus.stl]
2025-08-24 Updated USB Mode on Genos version
    [case_plus.stl]
2025-08-24 Updated Quad Encoder Case
    [case_plus.scad]
2025-08-28 Added indent in base for Stemma connector
    [case_plus.scad]
2025-08-29 Updated Encoder and Quad Encoder Shaft Cover
    [topcover_plus_all_quad_cover.scad, topcover_plus_all_quad_cover.stl]
2025-08-30 Added Quad Encoder Switch assignments
    [topcover_plus_all_quad_cover.scad]
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2025-08-30 Added counter sync holes for bottom screws
    [case.scad, case_logo.scad, case_plus.scad]
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2025-09-05 Changed quad encoder 3 to Vol 0 for uppers only
    [keymap.cfg]
2025-09-05 Updated key mappings, prevented VAR trigger following Shift Lock, and added preset to Quad Encoder volumes
    [keymap.cfg]
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2025-09-07 Case and Keycap updates
    [case_plus.scad, evm_transparent_keycap_insert.scad, keycap_clear_cover01.scad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]
2025-09-08 Updated quad top cover moving encoders space 1mm right
    [evm_keycap_topcover_clear.scad, evm_transparent_keycap_insert.scad, keymap.cfg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]
2025-09-09 Updated quad top cover moving encoders space 1mm right and down
    [topcover_plus_all_quad_cover.scad, topcover_plus_all_quad_cover.stl]
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2025-09-11 Updated readme and changes Variation key shift mode color to off white
    [keymap.cfg]
2025-09-11 Readme updated
    [keycap_clear_cover01.scad, keycap_topcover_clear.scad, transparent_keycap_insert.stl]
2025-09-15 Updated keymap.cfg adding macro definitions
    [keymap.cfg]
2025-09-18 Modified Macro dictionary to load from disk after modification by Config Editor
    [keymap.cfg]
2025-09-19 Keymap macros updated
    [keymap.cfg]
2025-10-09 Updated cases and keymap
    [case_logo.scad, case_logo.stl, case_plus.scad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]
2025-10-12 Updated EVM HS13 to handle counter clockwise encoders
    [case_logo.stl, case_plus.stl]
2025-10-13 Updated keymap adding variable support for encoder direction
    [keymap.cfg]
2025-10-16 Updated the readme
    [keymap.cfg]
2025-10-29 restructured the 3d print files
    [case.scad, case.stl, case_dev.scad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]
2025-10-31 Added graded adjustment of quad volumes
    [keymap.cfg]
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2025-11-14 Finalized Quad Encoder toggle and EncVol load from keymap.cfg
    [keymap.cfg]
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2025-11-17 Added Variables for Variation and Times to keymap.cfg
    [keymap-leigh.cfg]
2025-11-18 Added more config variables to keymap.cfg
    [keymap-leigh.cfg, keymap.cfg]
2025-11-19 Unified Added config variables in keymap.cfg across HS13 and HS13+
    [keymap-leigh.cfg, keymap.cfg]
